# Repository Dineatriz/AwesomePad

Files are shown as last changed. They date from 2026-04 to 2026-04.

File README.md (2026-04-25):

# AwesomePad
---

## Overview

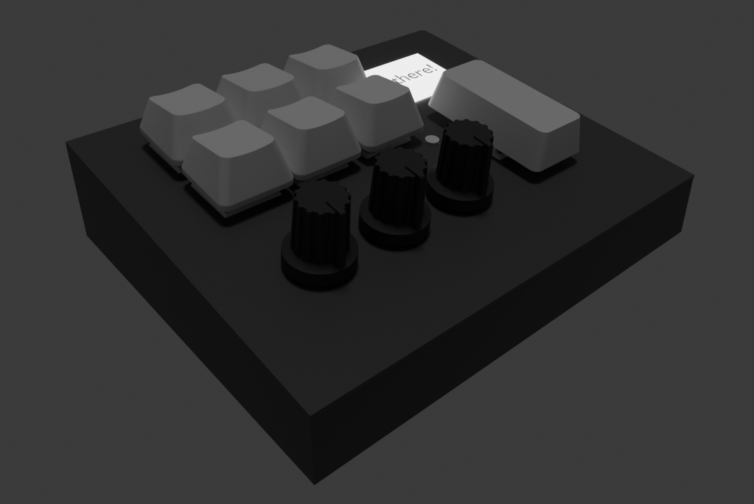
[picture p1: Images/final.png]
final


This macropad was made and designed to help gamers who frequently use Discord and people who do livestreams. With 6 customizable switches, a 2U switch with push-to-talk functionality, 3 configurable knobs, and an OLED panel, it can do almost anything the user wants.

---

## Schematic

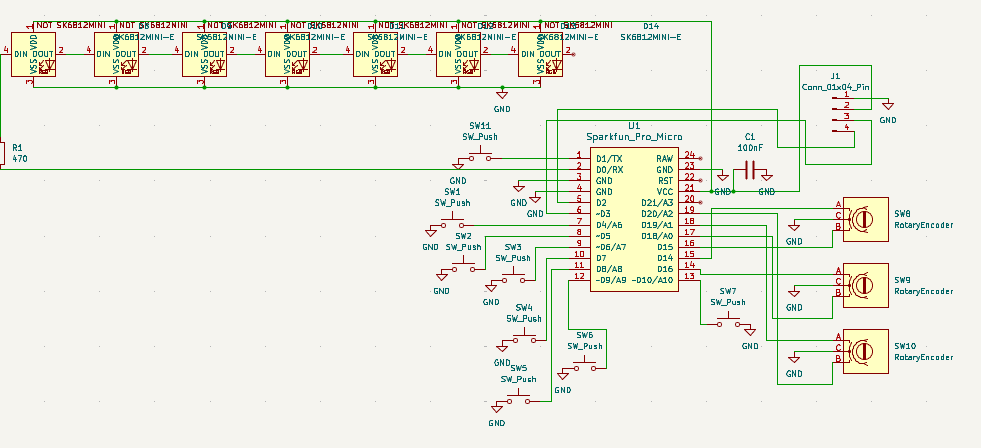
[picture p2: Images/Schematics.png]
Schematic


---

## PCB

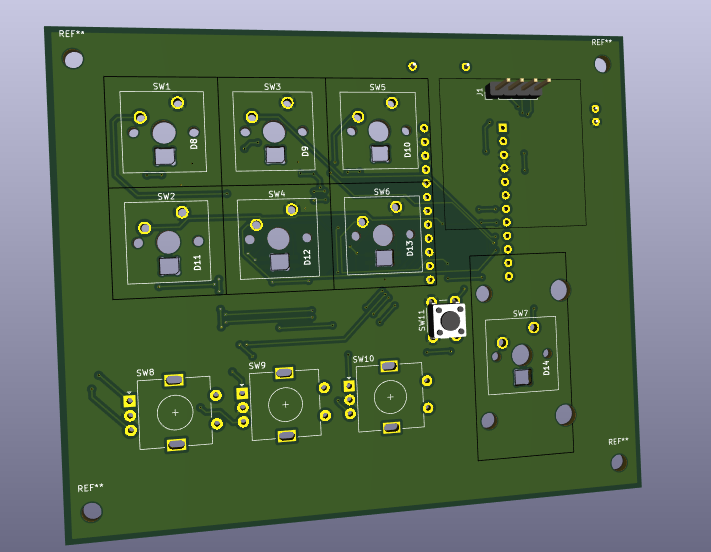
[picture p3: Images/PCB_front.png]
PCB_front

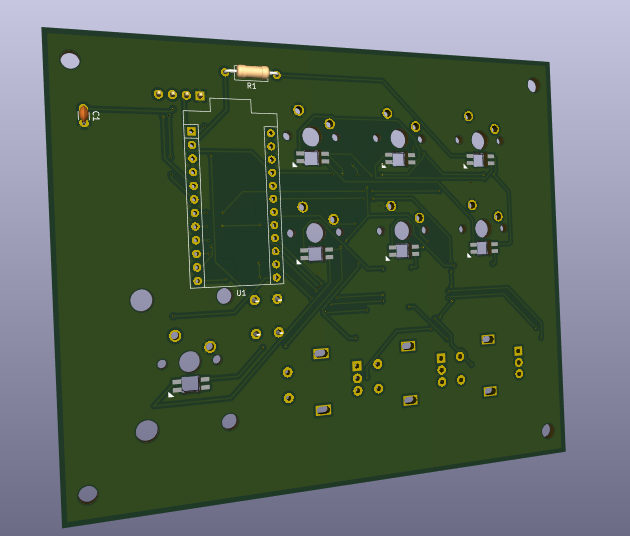
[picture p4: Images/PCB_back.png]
PCB_back


---

## Case

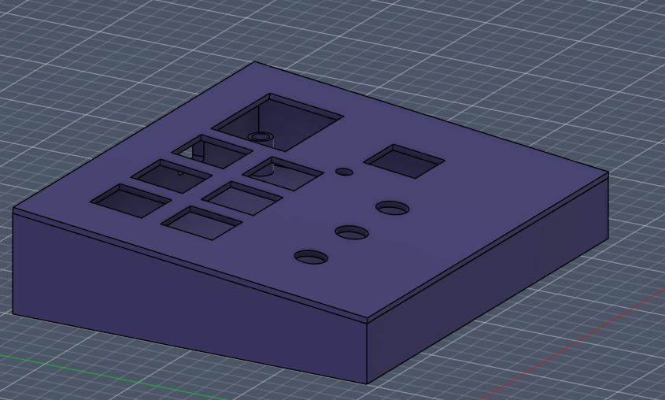
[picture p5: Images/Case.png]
Case Design

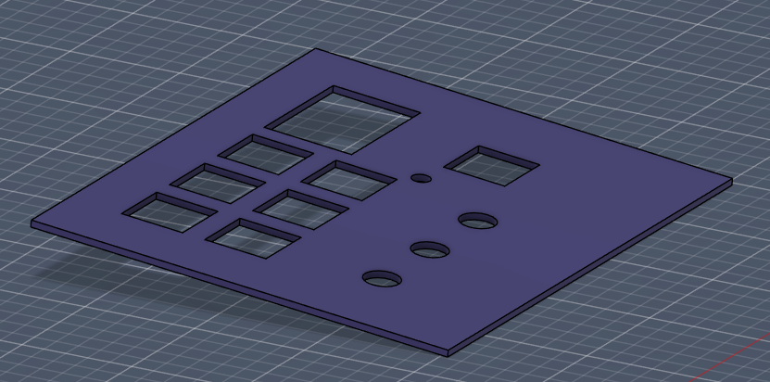
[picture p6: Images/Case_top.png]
Case Design

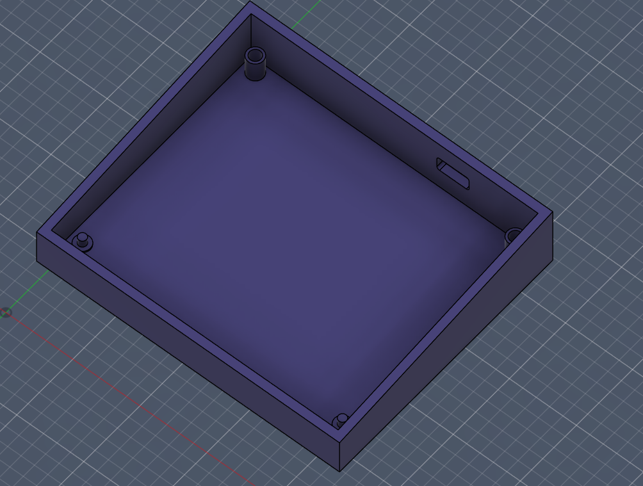
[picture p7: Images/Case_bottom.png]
Case Design


The case is 3D printed in 2 parts (Top + Bottom) and fits the PCB snugly with cutouts for all switches, the encoder, the OLED, knobs, and the USB-C port.

---

## BOM (Bill of Materials)

## Main Components
| Item | Qtd. | Name | Link | Price(USD)  |
| --- | ---- | --- | --- | --- |
| Pro Micro | 1 | **Pro Micro ATmega32U4 5V 16MHz USB-C 24 pin** | https://amzn.eu/d/027iGPug  | $10.68 |
| OLED Display | 1 | **OLED 0.96 inch SSD1306 I2C 4 pin** | https://amzn.eu/d/0ihcXsfb  | $9.49 |
| Rotary Encoder | 3 | **EC11 rotary encoder 20mm D shaft** | https://amzn.eu/d/0cy0BtVi  | $10.68 |
| Switches MX | 7 | **Cherry MX switches pack small / Gateron switches 10 pack** | https://amzn.eu/d/0iitvTCB  | $9.25 | 

## Interface
| Item | Qtd. | Name | Link | Price(USD)  | 
| --- | ---- | --- | --- | --- |
| Keycaps 1U | 6 | **1U keycaps MX individual PBT** | https://amzn.eu/d/078EwmKl | $10.68 |
| Keycap 2U | 1 | **2U keycap MX single keycap** | https://acesse.one/y47nhj1 | $1.09 |

## Structure
| Item | Qtd. | Name | Link | Price(USD)  |
| --- | ---- | --- | --- | --- |
| Screws | 6 | **M3 6mm screws Phillips** | https://amzn.eu/d/05gWZ59w  | $10.68 |
| Rubber feet  | 4 | **adhesive rubber feet silicone** | https://amzn.eu/d/0bTfMZw4  | $5.92 |

---

## Built by

**Dineatriz** — Hackclub 2026

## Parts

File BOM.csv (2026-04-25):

Item | Quantity | Name | Unit Price (€) | Total (€) | Link
Pro Micro | 1 | Pro Micro ATmega32U4 5V 16MHz USB-C 24 pin | 9.14 | 9.14 | https://amzn.eu/d/027iGPug
OLED Display | 1 | OLED 0.96 inch SSD1306 I2C 4 pin | 8.12 | 8.12 | https://amzn.eu/d/0ihcXsfb
Rotary Encoder Pack | 1 | EC11 rotary encoder 20mm D shaft (pack 3) | 9.14 | 9.14 | https://amzn.eu/d/0cy0BtVi
Switches Pack | 1 | Cherry MX / Gateron switches (pack) | 7.92 | 7.92 | https://amzn.eu/d/0iitvTCB
Keycaps 1U Pack | 1 | 1U keycaps MX individual PBT (pack) | 9.14 | 9.14 | https://amzn.eu/d/078EwmKl
Keycap 2U | 1 | 2U keycap MX single keycap | 0.93 | 0.93 | https://acesse.one/y47nhj1
Screws Pack | 1 | M3 6mm screws Phillips (pack) | 9.14 | 9.14 | https://amzn.eu/d/05gWZ59w
Rubber feet Pack | 1 | adhesive rubber feet silicone (pack) | 5.07 | 5.07 | https://amzn.eu/d/0bTfMZw4

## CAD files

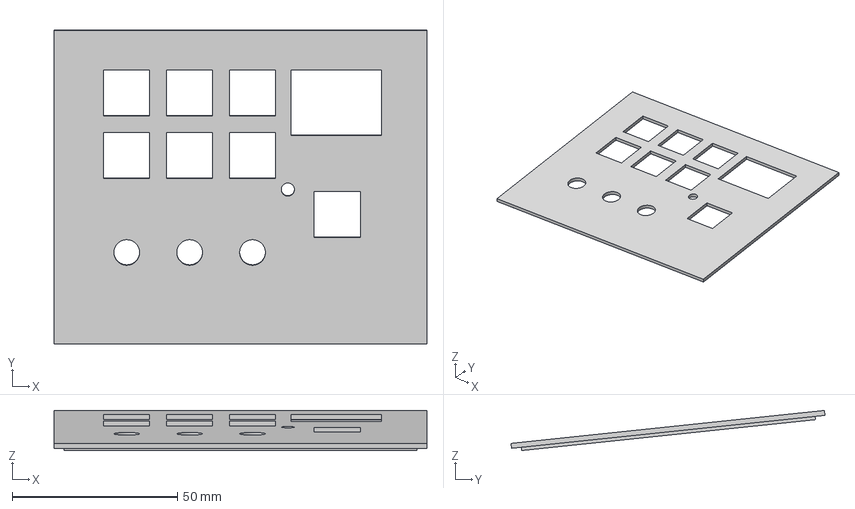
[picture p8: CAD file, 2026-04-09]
CAD/Top.step
113.0 x 95.1 x 12.2 mm

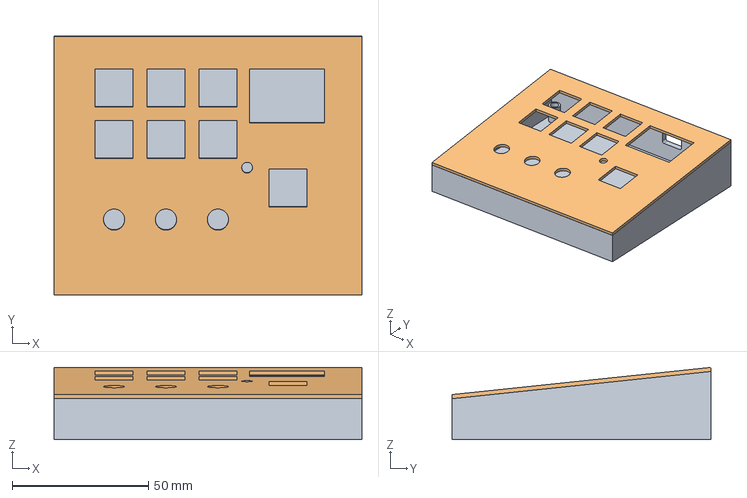
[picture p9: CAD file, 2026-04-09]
CAD/Enclosure.step
113.0 x 95.1 x 26.5 mm

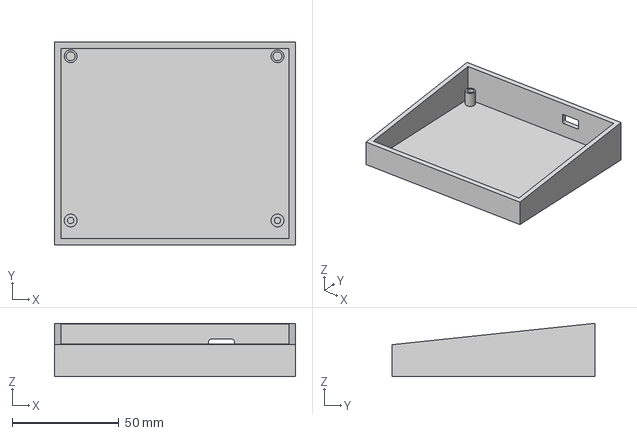
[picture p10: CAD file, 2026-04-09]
CAD/Bottom.step
113.0 x 95.0 x 25.0 mm

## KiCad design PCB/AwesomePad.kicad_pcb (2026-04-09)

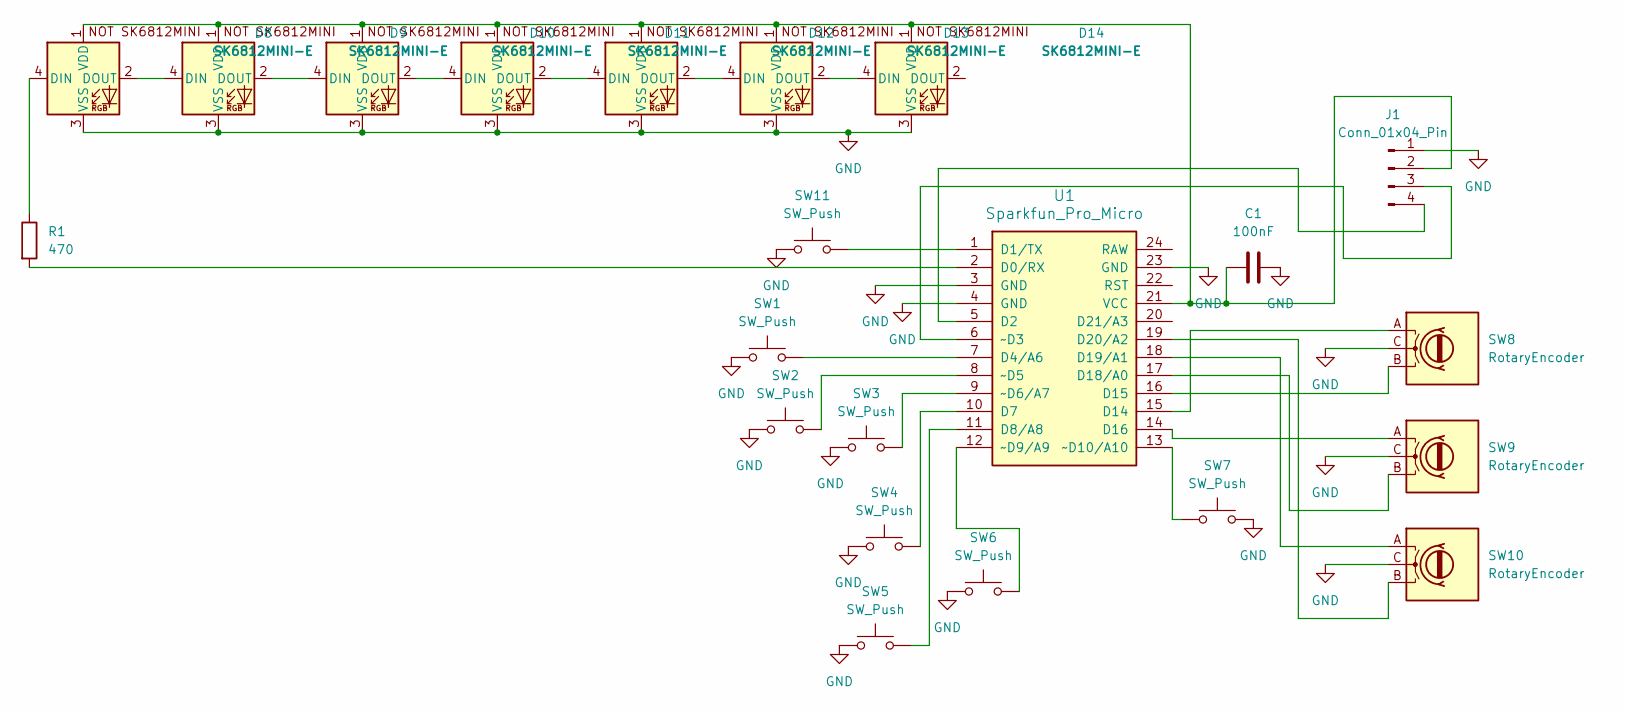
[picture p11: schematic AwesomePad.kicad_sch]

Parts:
C1: 100nF; C_Disc_D3.0mm_W1.6mm_P2.50mm
D8, D9, D10, D11, D12, D13, D14: SK6812MINI-E; SK6812MINI-E_fixed
J1: Conn_01x04_Pin; PinHeader_1x04_P2.54mm_Vertical
R1: 470; R_Axial_DIN0207_L6.3mm_D2.5mm_P10.16mm_Horizontal
SW1, SW2, SW3, SW4, SW5, SW6: SW_Push; SW_Cherry_MX_1.00u_PCB
SW7: SW_Push; SW_Cherry_MX_2.00u_Vertical_PCB
SW8, SW9, SW10: RotaryEncoder; RotaryEncoder_Alps_EC11E-Switch_Vertical_H20mm
SW11: SW_Push; SW_PUSH_6mm
U1: Sparkfun_Pro_Micro

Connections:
GND: C1.2, D8.3 (VSS), D9.3 (VSS), D10.3 (VSS), D11.3 (VSS), D12.3 (VSS), D13.3 (VSS), D14.3 (VSS), J1.1, SW1.1, SW2.1, SW3.1, SW4.1, SW5.1, SW6.1, SW7.2, SW8.C, SW9.C, SW10.C, SW11.1, U1.3 (GND), U1.4 (GND), U1.23 (GND)
unnamed: D8.4 (DIN), R1.1
unnamed: D8.2 (DOUT), D9.4 (DIN)
unnamed: D9.2 (DOUT), D10.4 (DIN)
unnamed: D10.2 (DOUT), D11.4 (DIN)
unnamed: C1.1, D8.1 (VDD), D9.1 (VDD), D10.1 (VDD), D11.1 (VDD), D12.1 (VDD), D13.1 (VDD), D14.1 (VDD), J1.2, U1.21 (VCC)
unnamed: D11.2 (DOUT), D12.4 (DIN)
unnamed: D12.2 (DOUT), D13.4 (DIN)
unnamed: D13.2 (DOUT), D14.4 (DIN)
unnamed: J1.3, U1.6 (~D3)
unnamed: J1.4, U1.5 (D2)
unnamed: R1.2, U1.2 (D0/RX)
unnamed: SW11.2, U1.1 (D1/TX)
unnamed: SW1.2, U1.7 (D4/A6)
unnamed: SW4.2, U1.10 (D7)
unnamed: SW5.2, U1.11 (D8/A8)
unnamed: SW8.A, U1.15 (D14)
unnamed: SW8.B, U1.16 (D15)
unnamed: SW9.A, U1.14 (D16)
unnamed: SW9.B, U1.17 (D18/A0)
unnamed: SW10.A, U1.18 (D19/A1)
unnamed: SW10.B, U1.19 (D20/A2)
unnamed: SW2.2, U1.8 (~D5)
unnamed: SW3.2, U1.9 (~D6/A7)
unnamed: SW6.2, U1.12 (~D9/A9)
unnamed: SW7.1, U1.13 (~D10/A10)

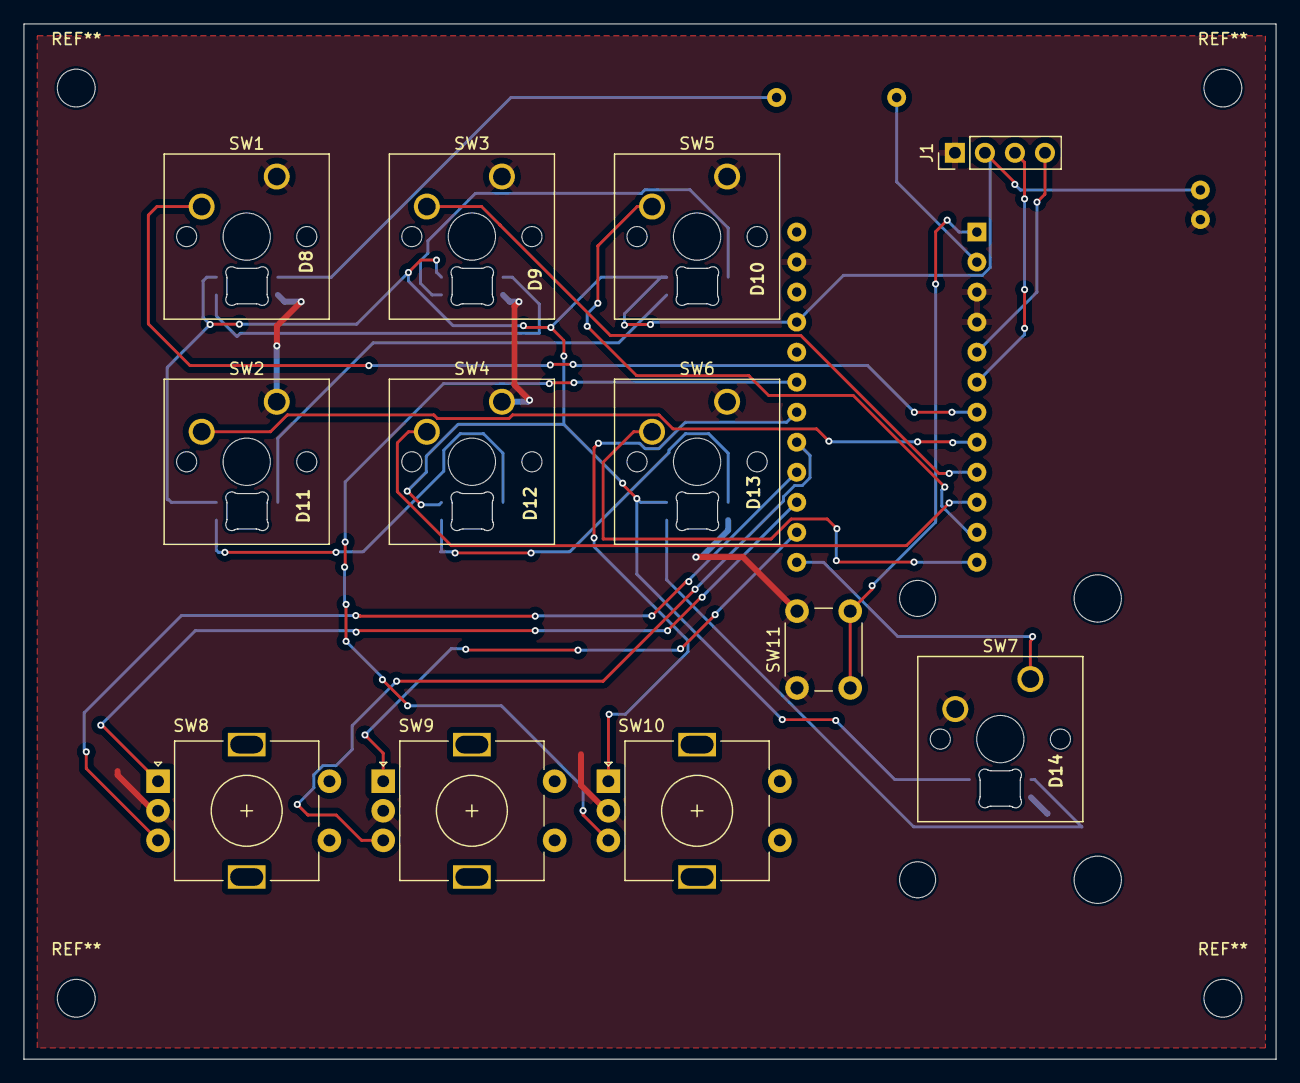
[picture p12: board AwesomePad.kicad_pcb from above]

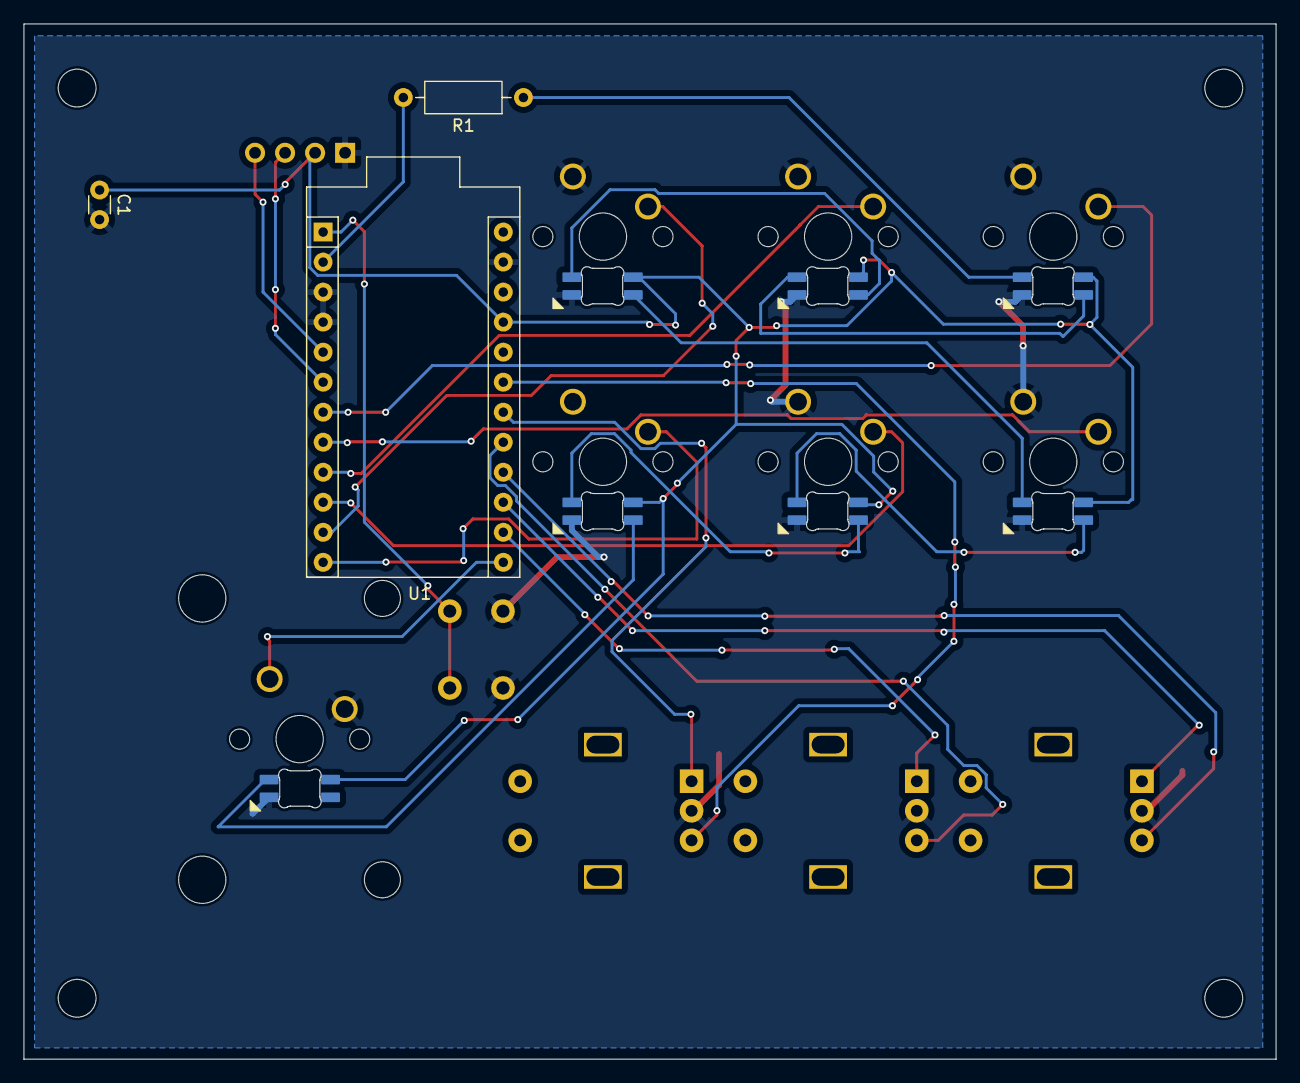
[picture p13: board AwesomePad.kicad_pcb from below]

Board: 2 copper layers, 105.9 x 87.6 mm, 22 parts (3 on the bottom side), 26 nets.

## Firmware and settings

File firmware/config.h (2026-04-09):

#pragma once

#define VENDOR_ID 0x1B4F // "MS"
#define PRODUCT_ID 0x9206 // "AS"
#define DEVICE_VER 0x0001
#define MANUFACTURER "Stasis"
#define PRODUCT "Stasis Macropad"

#define MATRIX_ROWS 1
#define MATRIX_COLS 8

#define DIRECT_PINS { \
    { D3, D4, C6, D7, B4, B5, B6, B7 } \
}

#define DIODE_DIRECTION COL2ROW

#define DEBOUNCE 5

#define ENCODER_RESOLUTION 4

#define RGB_DI_PIN D2
#define RGBLIGHT_LED_COUNT 6
#define RGBLIGHT_LIMIT_VAL 150
#define RGBLIGHT_DEFAULT_VAL 80
#define RGBLIGHT_HUE_STEP 8
#define RGBLIGHT_SAT_STEP 8
#define RGBLIGHT_VAL_STEP 8
#define RGBLIGHT_SLEEP
#define RGBLIGHT_EFFECT_BREATHING
#define RGBLIGHT_EFFECT_STATIC_LIGHT

#define OLED_DISPLAY_128X64
#define OLED_BRIGHTNESS 128
#define OLED_TIMEOUT 0
#define OLED_SCROLL_TIMEOUT 0
#define I2C1_CLOCK_SPEED 400000

#define LAYER_SYSTEM 0
#define LAYER_MEDIA 1
#define LAYER_VIRTUALDJ 2

#define OLED_ENCODER_FEEDBACK_TIMEOUT 2000

#define TAPPING_TERM 200

#define MOUSEKEY_DELAY 0
#define MOUSEKEY_INTERVAL 16
#define MOUSEKEY_WHEEL_DELAY 0
#define MOUSEKEY_WHEEL_INTERVAL 80
#define MOUSEKEY_WHEEL_MAX_SPEED 8

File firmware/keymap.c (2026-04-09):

// ============================================================
// STASIS MACROPAD - keymap.c
// 3 Modos: SYSTEM / MEDIA / VIRTUALDJ
// Hardware: Pro Micro ATmega32U4
// ============================================================

#include QMK_KEYBOARD_H
#include "oled_display.h"
#include <string.h>

// ============================================================
// ESTADO GLOBAL
// ============================================================

uint8_t  current_mode         = 0;      // 0=SYSTEM, 1=MEDIA, 2=VIRTUALDJ
bool     mic_muted            = true;   // Começa como mudo
int8_t   encoder_left_val     = 50;     // Valores 0-100
int8_t   encoder_center_val   = 50;
int8_t   encoder_right_val    = 50;
uint32_t encoder_feedback_timer = 0;
uint8_t  encoder_feedback_id  = 0;

// ============================================================
// DEFINIÇÃO DE KEYCODES CUSTOMIZADOS
// ============================================================

enum custom_keycodes {
    KC_MODE_SWITCH = SAFE_RANGE,  // D1/TX: troca de modo cíclica
    KC_PTT_LARGE,                 // D10/A10: Push-to-Talk / DJ Play
};

// ============================================================
// LAYOUT — Direct Pins (1 linha, 8 colunas)
//
// Index: [ 0          1          2          3
//           4          5          6          7      ]
// Pino:  [ D1/TX      D4/A6      D5         D6/A7
//           D7         D8/A8      D9/A9      D10/A10]
// Func:  [ ModeSwitch SW1        SW2        SW3
//           SW4        SW5        SW6        PTT    ]
//
// Encoders geridos por encoder_update_user() — fora da matriz
// ============================================================

const uint16_t PROGMEM keymaps[][MATRIX_ROWS][MATRIX_COLS] = {

    // --------------------------------------------------------
    // LAYER 0: SYSTEM / Produtividade
    // --------------------------------------------------------
    [0] = LAYOUT(
     // ModeSwitch   SW1            SW2            SW3
        KC_MODE_SWITCH, LCTL(KC_C), LCTL(KC_V),    LCTL(KC_X),
     // SW4             SW5         SW6             PTT
        KC_PSCR,        LALT(KC_F4),LCTL(LSFT(KC_ESC)), KC_PTT_LARGE
    ),

    // --------------------------------------------------------
    // LAYER 1: MEDIA & Navi
    // --------------------------------------------------------
    [1] = LAYOUT(
     // ModeSwitch   SW1       SW2        SW3
        KC_MODE_SWITCH, KC_MPRV, KC_MPLY,  KC_MNXT,
     // SW4             SW5      SW6       PTT
        KC_CALC,        KC_WBAK, KC_WFWD,  KC_PTT_LARGE
    ),

    // --------------------------------------------------------
    // LAYER 2: VirtualDJ
    // --------------------------------------------------------
    [2] = LAYOUT(
     // ModeSwitch   SW1    SW2    SW3
        KC_MODE_SWITCH, KC_F1, KC_F2, KC_F3,
     // SW4             SW5    SW6    PTT
        KC_F4,          KC_F5, KC_F6, KC_PTT_LARGE
    ),
};

// ============================================================
// CORES RGB POR MODO
// ============================================================

typedef struct {
    uint8_t r, g, b;
} rgb_color_t;

// Cores dos 6 LEDs para cada modo
static const rgb_color_t PROGMEM mode_colors[3][6] = {
    // SYSTEM: Branco/Ciano alternado
    [0] = {
        {200, 200, 200}, {0, 200, 200},  {200, 200, 200},
        {0,   200, 200}, {200, 200, 200},{0,   200, 200},
    },
    // MEDIA: Roxo/Rosa alternado
    [1] = {
        {180, 0, 200},   {200, 0, 120},  {180, 0, 200},
        {200, 0, 120},   {180, 0, 200},  {200, 0, 120},
    },
    // VIRTUALDJ: 3 Azuis / 3 Vermelhos
    [2] = {
        {0,   0,   200}, {0,   0,   200}, {0,   0,   200},
        {200, 0,   0},   {200, 0,   0},   {200, 0,   0},
    },
};

static void apply_rgb_mode(uint8_t mode) {
    for (uint8_t i = 0; i < 6; i++) {
        uint8_t r = pgm_read_byte(&mode_colors[mode][i].r);
        uint8_t g = pgm_read_byte(&mode_colors[mode][i].g);
        uint8_t b = pgm_read_byte(&mode_colors[mode][i].b);
        rgblight_setrgb_at(r, g, b, i);
    }
}

// ============================================================
// INICIALIZAÇÃO
// ============================================================

void keyboard_post_init_user(void) {
    // Ativar layer 0
    layer_clear();
    layer_on(0);

    // RGB: modo breathing no início
    rgblight_enable();
    rgblight_mode(RGBLIGHT_MODE_BREATHING + 2);  // breathing médio
    apply_rgb_mode(0);
}

// ============================================================
// TROCA DE MODO
// ============================================================

static void switch_mode(void) {
    current_mode = (current_mode + 1) % 3;

    // Trocar layer
    layer_clear();
    layer_on(current_mode);

    // Aplicar LEDs do novo modo
    apply_rgb_mode(current_mode);

    // No modo SYSTEM e MEDIA: breathing; no DJ: estático
    if (current_mode == 2) {
        rgblight_mode(RGBLIGHT_MODE_STATIC_LIGHT);
    } else {
        rgblight_mode(RGBLIGHT_MODE_BREATHING + 2);
    }
}

// ============================================================
// KEYCODES CUSTOMIZADOS
// ============================================================

bool process_record_user(uint16_t keycode, keyrecord_t *record) {
    switch (keycode) {

        // ---- Troca de modo cíclica (SW11) ----
        case KC_MODE_SWITCH:
            if (record->event.pressed) {
                switch_mode();
            }
            return false;

        // ---- PTT / Switch Grande (SW7) ----
        case KC_PTT_LARGE:
            if (current_mode == 0 || current_mode == 1) {
                // Modos 0 e 1: Discord Push-to-Talk
                // Pressionar E soltar ambos enviam Ctrl+Shift+M
                if (record->event.pressed) {
                    mic_muted = !mic_muted;  // toggle visual
                    tap_code16(LCTL(LSFT(KC_M)));
                } else {
                    tap_code16(LCTL(LSFT(KC_M)));
                }
            } else {
                // Modo 2 (VirtualDJ): Play/Pause = Espaço
                if (record->event.pressed) {
                    tap_code(KC_SPC);
                }
            }
            return false;

        default:
            return true;
    }
}

// ============================================================
// ENCODERS
// Mapeamento:
//   Encoder 0 = Esquerdo  (SW8)
//   Encoder 1 = Central   (SW9)
//   Encoder 2 = Direito   (SW10)
// ============================================================

static void clamp_val(int8_t *val, int8_t delta) {
    *val += delta;
    if (*val > 100) *val = 100;
    if (*val < 0)   *val = 0;
}

static void encoder_feedback(uint8_t id) {
    encoder_feedback_id    = id;
    encoder_feedback_timer = timer_read32();
}
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

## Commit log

2026-04-09 Add AwesomePad.kicad_pcb file
    [AwesomePad.kicad_pcb]
2026-04-09 Add AwesomePad schematic file
    [AwesomePad.kicad_sch]
2026-04-09 Enhance README with detailed product information
    Expanded the README to include an overview, schematic, PCB, case details, BOM, interface, and structure sections for the AwesomePad macropad.
2026-04-09 Rename Captura de ecrã 2026-04-08 163945.png to PCB_front
2026-04-09 Rename Captura de ecrã 2026-04-09 003926.png to Schematics
2026-04-09 Rename Captura de ecrã 2026-04-09 002350.png to Case
2026-04-09 Rename Captura de ecrã 2026-04-09 002343.png to Case_top
2026-04-09 Rename Captura de ecrã 2026-04-09 002323.png to Case_bottom
2026-04-09 Rename Captura de ecrã 2026-04-08 164000.png to PCB_back
2026-04-25 Add prices to BOM components in README
    Updated BOM section to include prices for components.
2026-04-25 Rename Captura de ecrã 2026-04-25 180546.png to final
2026-04-25 Change case image in README
    Updated the image in the README to the final design.
